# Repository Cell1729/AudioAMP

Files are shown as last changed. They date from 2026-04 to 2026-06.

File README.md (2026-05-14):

# AUDIOAMP

ヘッドフォンアンプの設計記録。

## 仕様

- INPUT : 3.5mmステレオジャック
- OUTPUT : 3.5mmステレオジャックと6.3mmステレオジャックをスイッチで切り替え
> 6.3mmOUTのみ変更
- ハイレゾに対応させる
- 出来る限り安くする

## 回路図

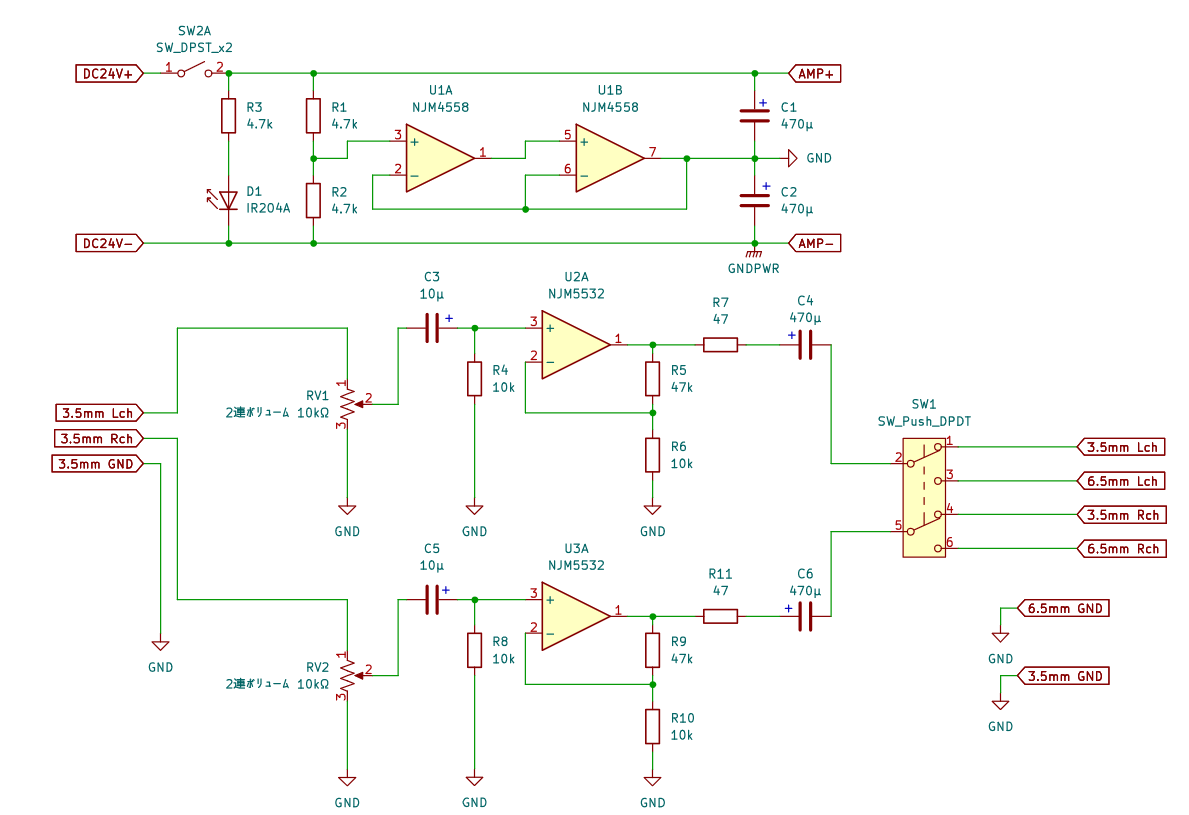
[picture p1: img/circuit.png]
circuit


### 特性

- 5.5倍利得
> 利得3倍に変更(20k/10k+1=3倍)
- 電源投下で緑のLEDを光らせる

## 部品

## 部品リスト

| 部品名 | 型番 | 数量 | 単価 | 小計 | 商品URL |
| :--- | :--- | :---: | :---: | :---: | :--- |
| アンプ | NJM5532DD | 1 | 90 | 90 | [リンク](https://akizukidenshi.com/catalog/g/g117706/) |
| アンプ 電源用 | NJM4558DD | 1 | 30 | 30 | [リンク](https://akizukidenshi.com/catalog/g/g111236/) |
| 小型2連ボリューム 10kΩA | JH16T2A103L20KC | 1 | 130 | 130 | [リンク](https://akizukidenshi.com/catalog/g/g116478/) |
| つまみ | ABS-28 | 1 | 30 | 30 | [リンク](https://akizukidenshi.com/catalog/g/g100253/) |
| 24VACアダプタ | AD-B240P100 | 1 | 1250 | 1250 | [リンク](https://akizukidenshi.com/catalog/g/g110658/) |
| ACアダプタコネクタ | MJ-14 | 1 | 70 | 70 | [リンク](https://akizukidenshi.com/catalog/g/g106342/) |
| 3.5mmステレオジャック | MJ-073H | 2 | 120 | 240 | [リンク](https://akizukidenshi.com/catalog/g/g106257/) |
| 6.3mmステレオジャック | MJ-189LP | 1 | 230 | 230 | [リンク](https://akizukidenshi.com/catalog/g/g106765/) |
| イヤホンジャック切り替え | - | 1 | 30 | 30 | [リンク](https://akizukidenshi.com/catalog/g/g115706/) |
| 電源用LED | OSG8HA3Z74A | 1 | 10 | 10 | [リンク](https://akizukidenshi.com/catalog/g/g111637/) |
| 電源スイッチ | 1MS1-T1-B1-M1-Q-N | 1 | 120 | 120 | [リンク](https://akizukidenshi.com/catalog/g/g103774/) |
| 4.7k抵抗 100本入り1% | MFS25F4K7B | 1 | 250 | 250 | [リンク](https://akizukidenshi.com/catalog/g/g108546/) |
| 10k抵抗 100本入り 1% | MFS25F10KB | 1 | 250 | 250 | [リンク](https://akizukidenshi.com/catalog/g/g108550/) |
| 47抵抗 100本入り 1% | MFS25F47RB | 1 | 250 | 250 | [リンク](https://akizukidenshi.com/catalog/g/g108518/) |
| 470μF 電解コンデンサ | 35ZLH470MEFC10X16 | 4 | 40 | 160 | [リンク](https://akizukidenshi.com/catalog/g/g102719/) |
| 10μF 電解コンデンサ | 50PX10MEFC5X11 | 2 | 10 | 20 | [リンク](https://akizukidenshi.com/catalog/g/g117897/) |
| アンプ ICソケット | 2227-8-3 | 1 | 110 | 110 | [リンク](https://akizukidenshi.com/catalog/g/g100017) |
| ユニバーサル基板 | - | 2 | 100 | 200 | [リンク](https://akizukidenshi.com/catalog/g/g100517/) |

合計金額: 3,470円

### ユニバーサル基板

[片面グラス・ユニバーサル基板 C type 72x47.5mm](https://akizukidenshi.com/catalog/g/g100517/)

## 入出力波形

> どの波形も緑が入力、青または赤が出力

### サンプル1

条件 : 0.5[V] 1[kHz]

Left Ch

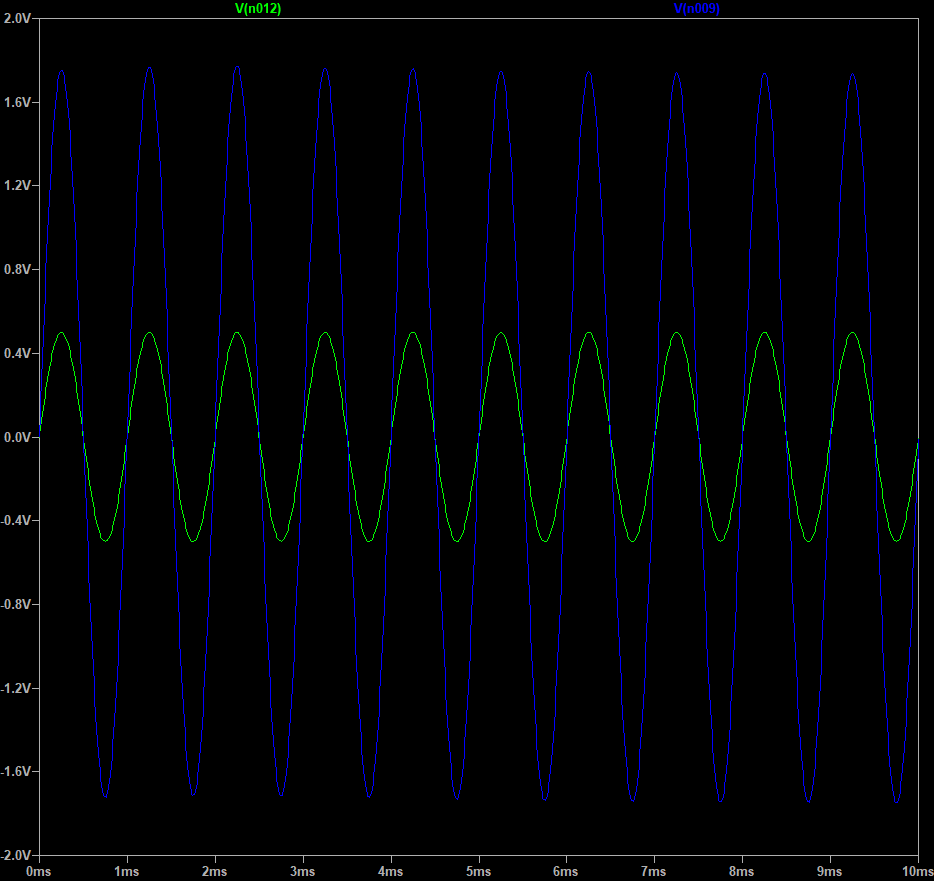
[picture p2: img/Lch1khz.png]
Lch


Right Ch

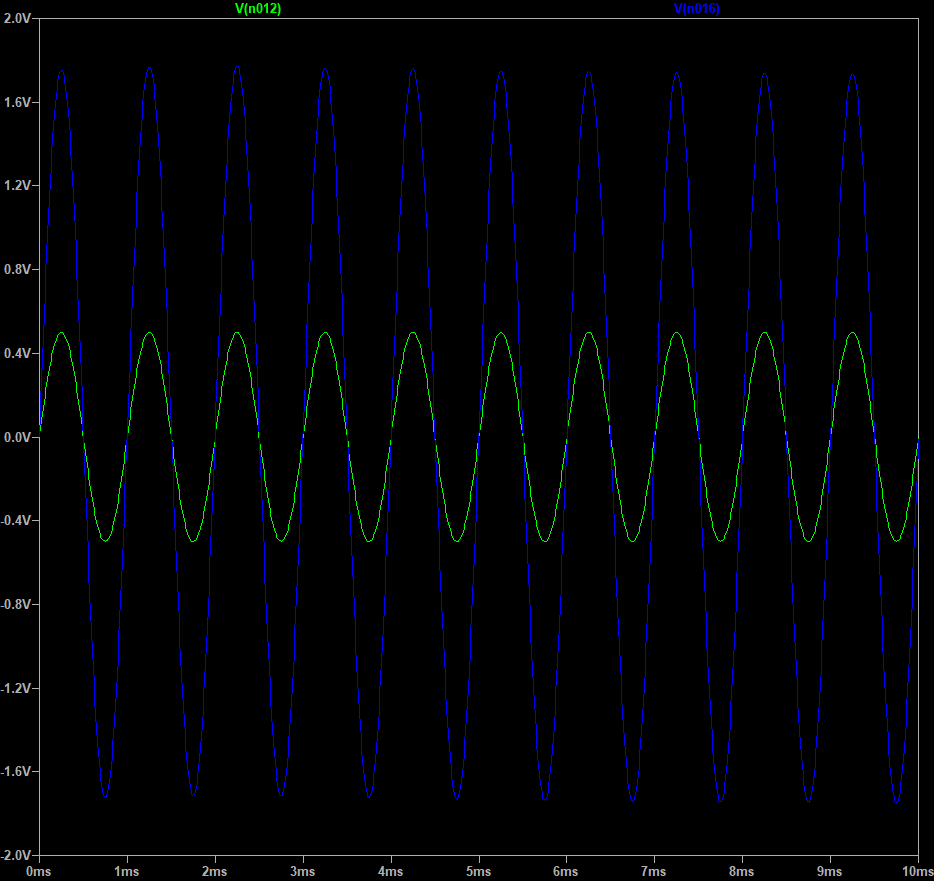
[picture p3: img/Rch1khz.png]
Rch


### サンプル2

条件 : 0.5[V] 96[kHz]

Left Ch

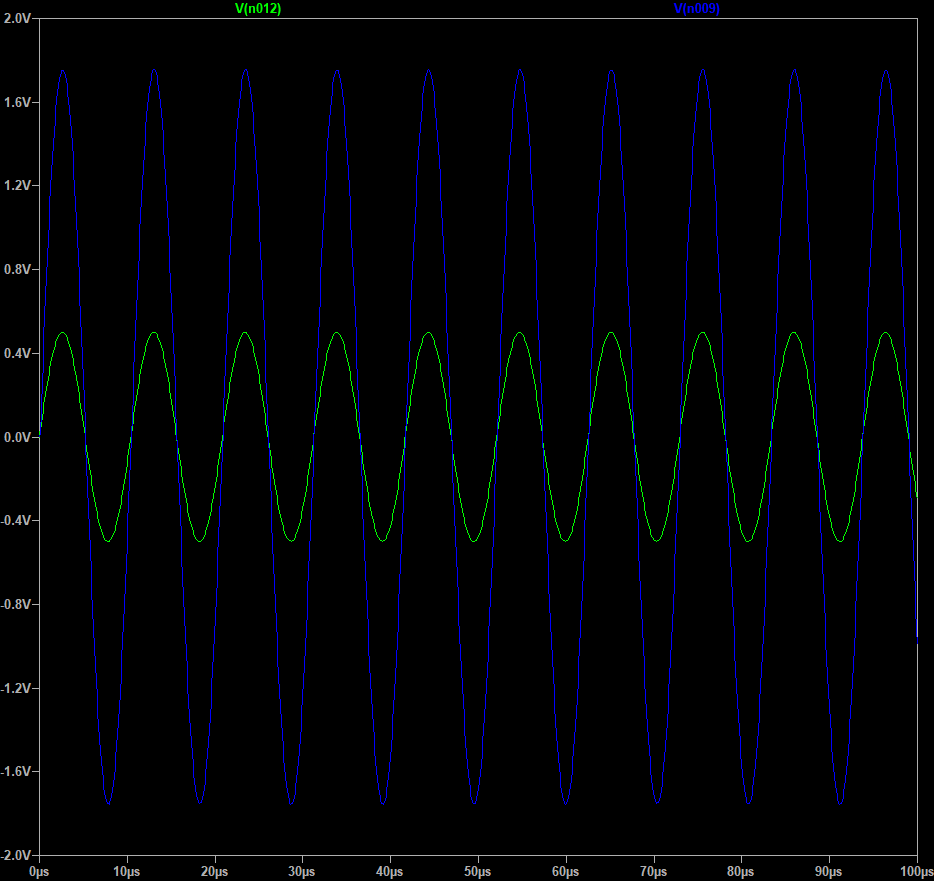
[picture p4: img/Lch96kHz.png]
LchHires


Right Ch

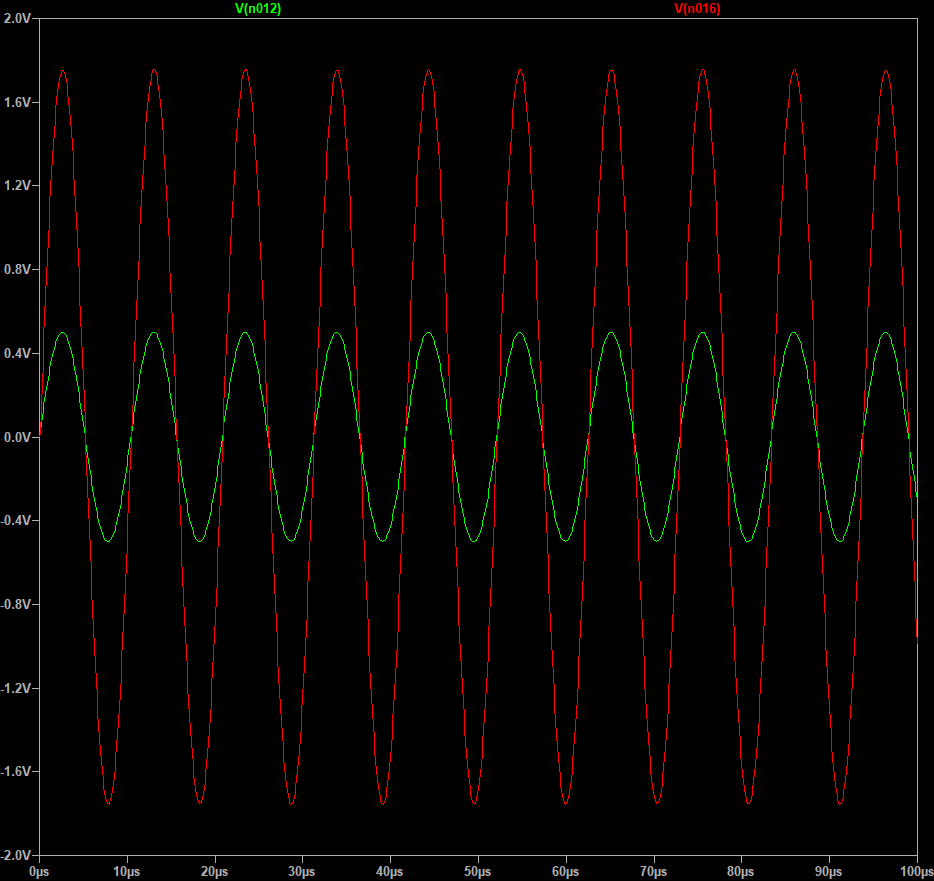
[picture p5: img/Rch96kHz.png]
RchHires


## その他

## `45kΩ`抵抗について

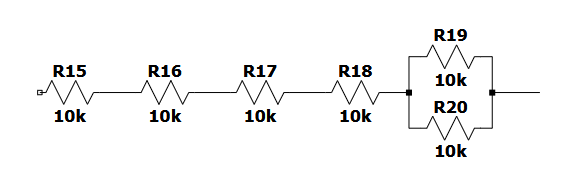
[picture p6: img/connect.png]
RConnect


このように上の図のように接続すれば抵抗値は
```
10k+10k+10k+10k+(10k*10k)/(10k+10k)=45k
```

## 基板構成

- 電源回路用基板
- アンプ搭載基板

## REF

- [AE-KIT45-HPAキット](https://akizukidenshi.com/goodsaffix/AE-KIT45-HPA.pdf)
- [電子パーツのコツ/ユニバーサル基板に挑戦](https://article.murata.com/ja-jp/article/challenge-the-universal-board)

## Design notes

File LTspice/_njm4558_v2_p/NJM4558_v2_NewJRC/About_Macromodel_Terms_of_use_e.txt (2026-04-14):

About Macromodel - Terms of use -
---------------------------------
1．Introduction

Our Macromodel (for use with PSpice) is a simulation program and not for use in actual product operation. 
It is not an alternative to the actual product. Please use this Macromodel to assist in the actual product operation check.

2．Special instruction

Nisshinbo Micro Devices is not responsible for changes, omissions, inaccuracies, and designs caused by the product Macromodel. 
Moreover, Nisshinbo Micro Devices does not take any responsibility if customers use this information for other purposes.
Nisshinbo Micro Devices requires customers to take full responsibility for their use of any information acquired through Macromodel. 
In addition, Nisshinbo Micro Devices does not give consent agreement or patent rights with regards to circuits described 
in relevant documents.

3．Usage and operating requirements

3-1．Operating requirements

Our Macromodel and related information have been created for use with OrCAD/Pspice, which is produced by Cadence Design Systems, Inc. 
in the United States. 
Nisshinbo Micro Devices is not liable for performance of the Macromodelin all computer systems.

3-2.Conditions of use

The product Macromodel should be used under agreement of the conditions contained below.

i. The product Macromodel is offered with product-specific, present quality. 
Nisshinbo Micro Devices does not take responsibility for Macromodel operation once Macromodel is integrated into customers’ 
circuits or systems.

ii. The product Macromodel is subject to change without notice. Please refer to the latest version of data-sheet or delivery specifications 
for detailed information regarding each product.

Update October 01,2021

---------------------------------
Nisshinbo Micro Devices Inc.

(C) Nisshinbo Micro Devices Inc. All Rights Reserved.

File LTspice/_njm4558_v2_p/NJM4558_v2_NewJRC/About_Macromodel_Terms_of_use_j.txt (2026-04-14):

マクロモデル利用規約
---------------------------------
1．はじめに

日清紡マイクロデバイス株式会社（以下「当社」といいます。）が提供する製品マクロモデル （=PSpice用マクロモデル）は、
実製品の動作を模擬できる手段の一つです。 
ただし、製品マクロモデルを使った回路シミュレーションは、実製品を用いた 試作基板などによる評価方法の代替とすることを
目的としておりません。 あくまで実製品の動作を確認するための一助としてお使いください。

2．特記事項

製品マクロモデルおよび関連情報は、正しい情報であるという前提で 提供していますが、
当社は、製品マクロモデルから生ずる変更、省略、不正確さ、 または設計に関して責任を負わないものとします。 
また、当社は、この情報を他の目的に利用した場合の責任も負わないものとし、 この情報の使用は全て利用者の自己責任とみなします。 
なお、当社は、関連文書中に記載されている回路に関して、利用許諾または 特許権を付与するものではありません。

3．ご利用にあたって

3-1．動作環境

当社が提供する製品マクロモデルおよび関連情報は、米Cadence社製の OrCAD/PSpiceで用いることを目的に作成しています。 
製品マクロモデル化にあたっては充分な注意を払っておりますが、全ての コンピュータ・システム上での正常動作に対して責任を負いかねます。

3-2．利用条件

製品マクロモデルは、以下のご利用条件にご同意の上、これをご利用ください。

ⅰ．製品マクロモデルは製品固有の現状品質で提供され、お客様の回路または システムと組み合わせた時の製品マクロモデルの動作に対して、
当社はいかなる 責任も一切負いかねます。
ⅱ．当社は、予告なく製品マクロモデルを変更することがあります。 個別製品の詳細情報は、最新版のデータシートまたは納入仕様書を 
参照してください。

4．その他

米Cadence社製のOrCAD/PSpiceを用い、かつ、その国内代理店である イノテック株式会社（https://www.innotech.co.jp/products/orcad/)と
OrCAD/PSpiceについて 保守契約締結をされているお客様につきましては、当社が提供する製品マクロモデルの PSpice上での使用方法について、
イノテック株式会社より技術支援が受けられます。

2021年10月1日更新

---------------------------------
日清紡マイクロデバイス株式会社

・本文書の記載内容は予告なく変更することがあります。
・本文書に記載されている、社名、商品名などは各社の商標または登録商標です。
・本文書の掲載内容を許可なく複製、転載する事を禁止いたします。
(C) Nisshinbo Micro Devices Inc. All Rights Reserved.

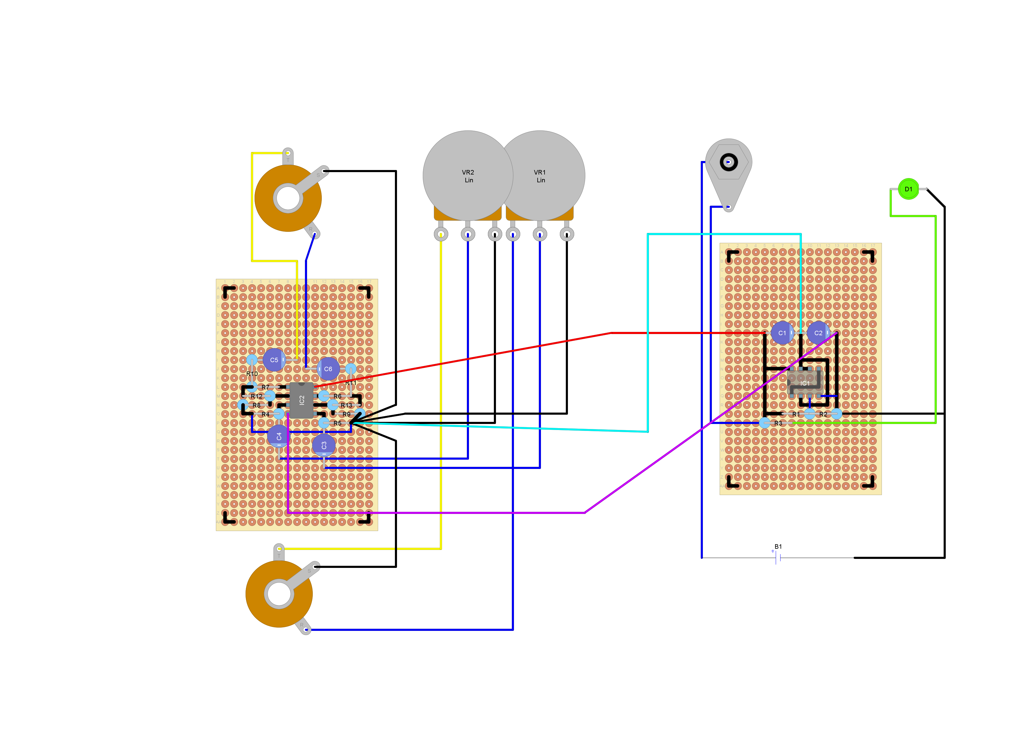
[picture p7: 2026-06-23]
layout/layout_real.png

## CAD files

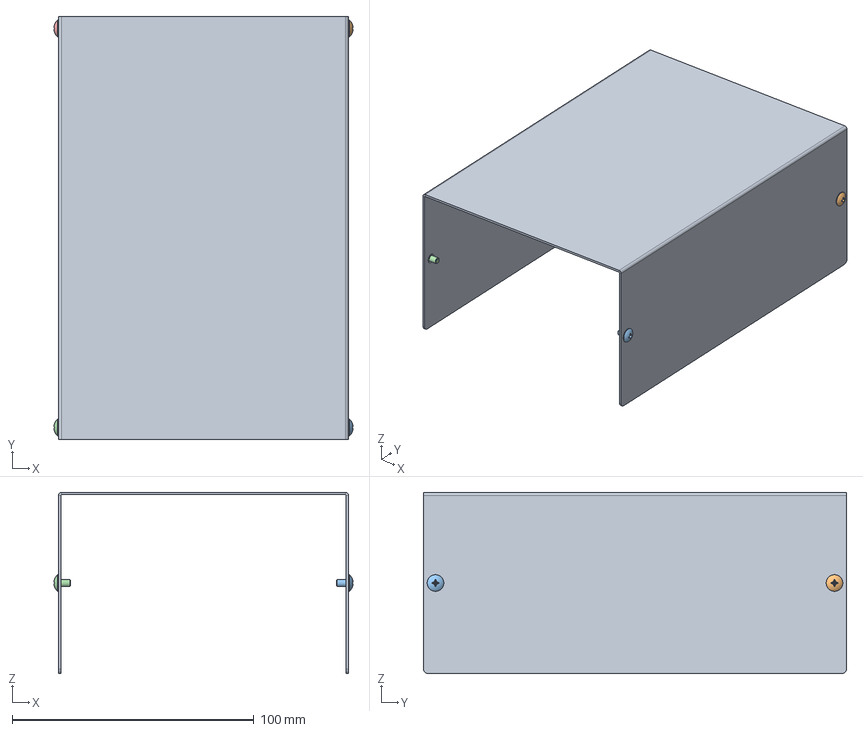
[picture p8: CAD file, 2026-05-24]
case/CAD/case.FCStd
123.6 x 175.0 x 75.0 mm
MB12-8-18_cover
M3x5
M3x001
M3x002
M3x003

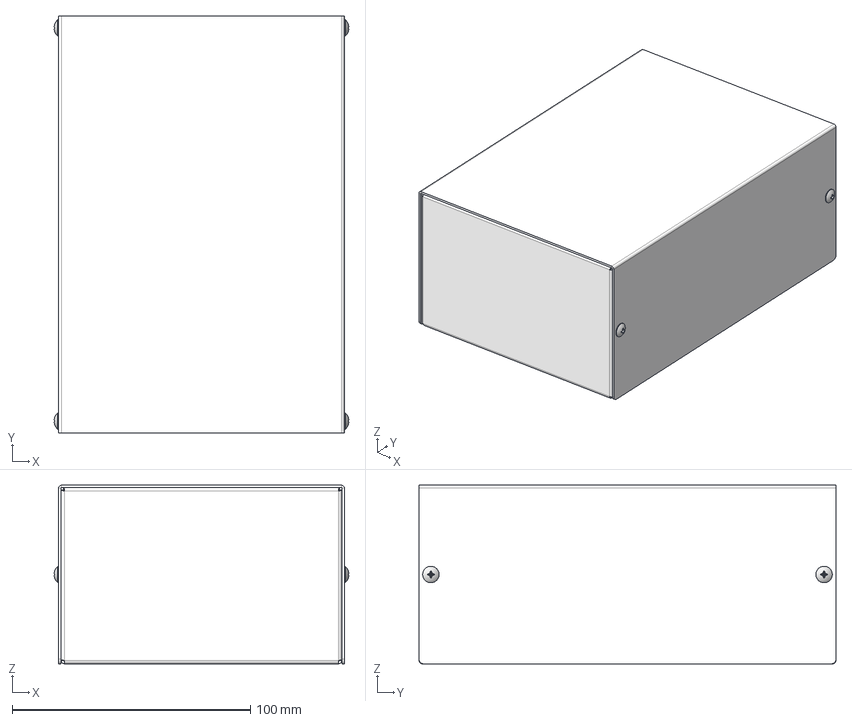
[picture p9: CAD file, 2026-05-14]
case/CAD/MB12-8-18.stp
123.6 x 175.0 x 75.0 mm
MB12-8-18_cover
MB12-8-18_ｼｬｰｼ
M3x5 x 4

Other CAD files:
case/case.dxf

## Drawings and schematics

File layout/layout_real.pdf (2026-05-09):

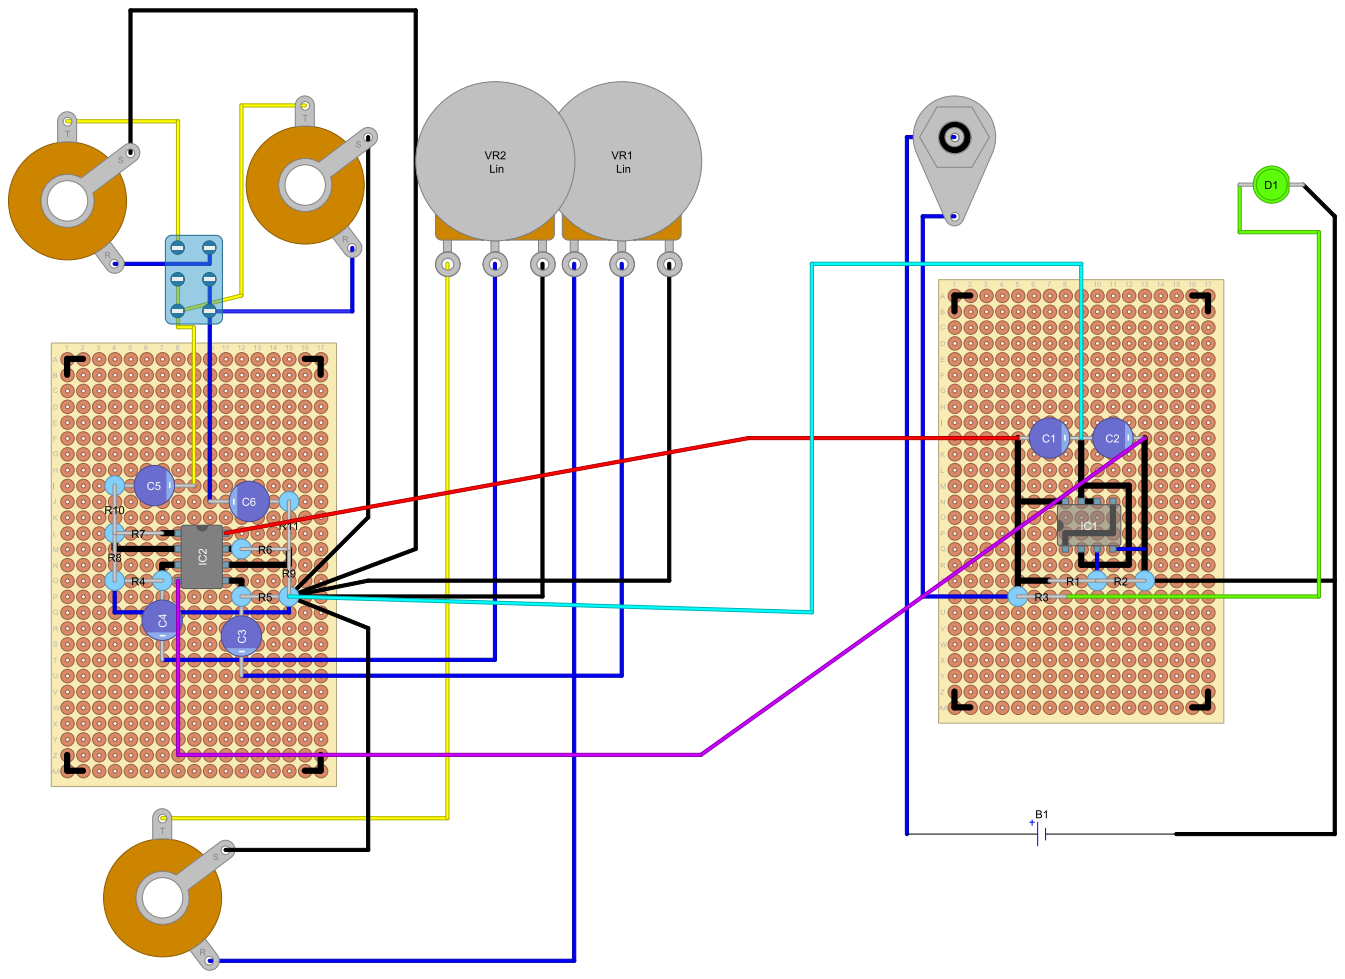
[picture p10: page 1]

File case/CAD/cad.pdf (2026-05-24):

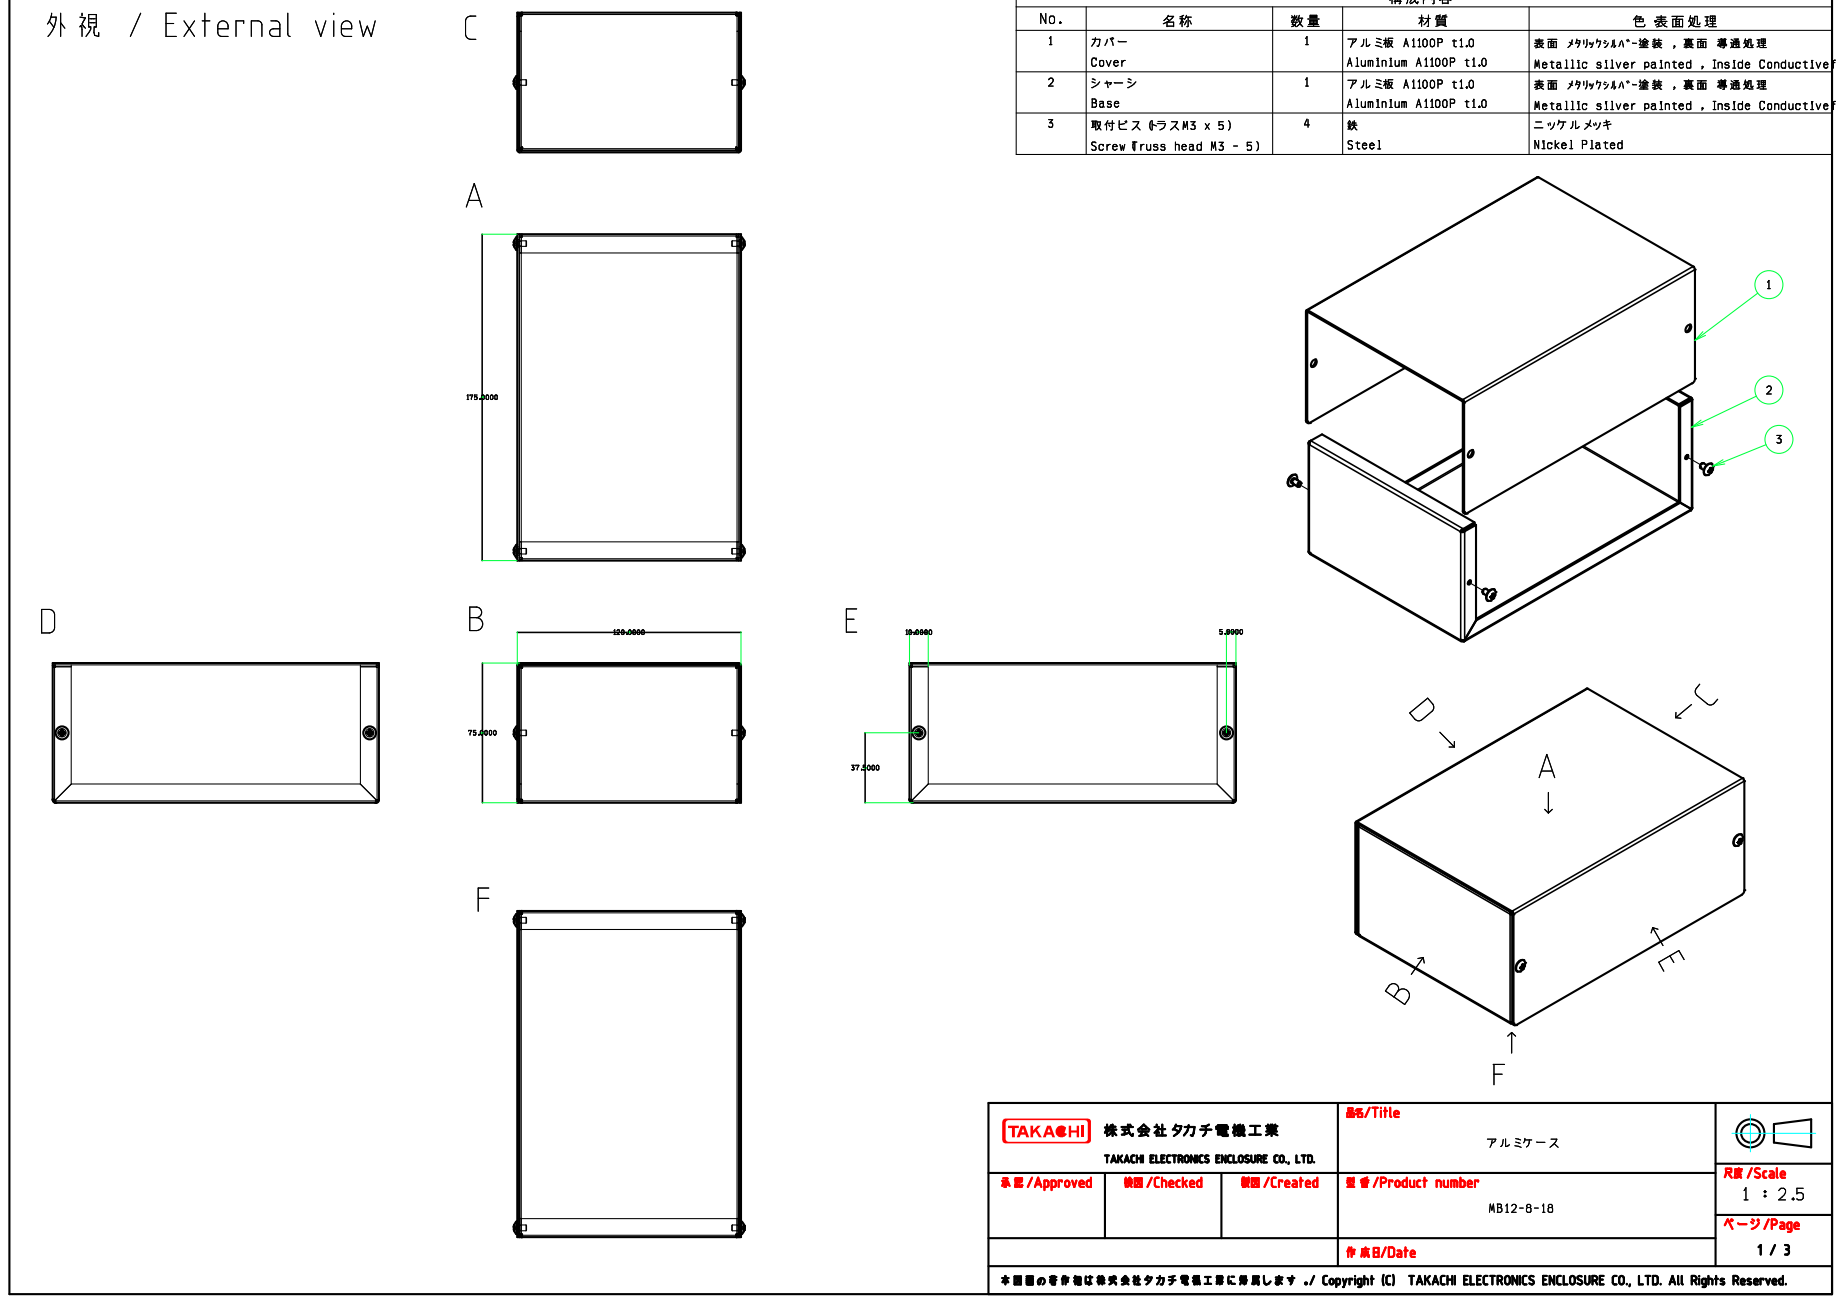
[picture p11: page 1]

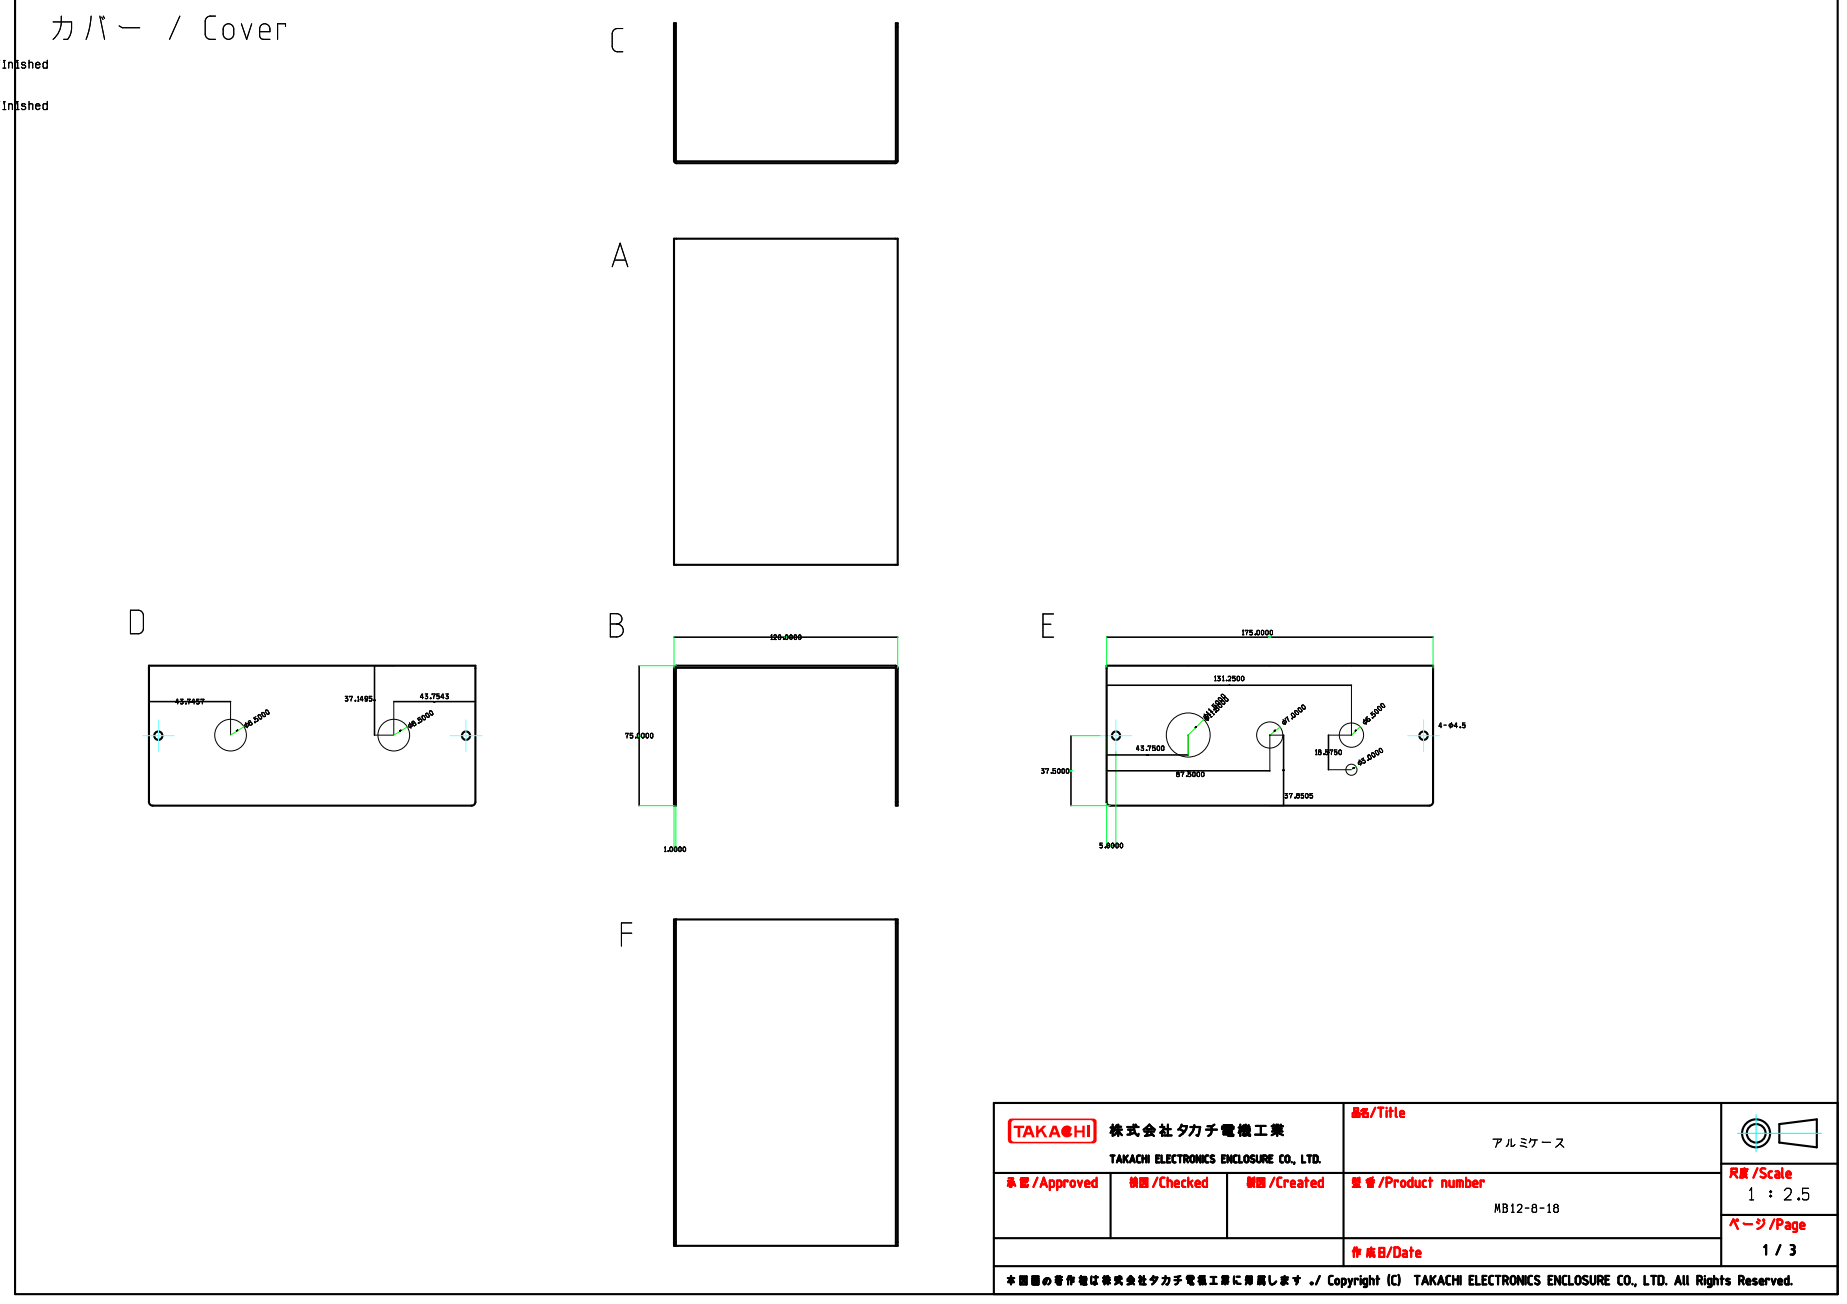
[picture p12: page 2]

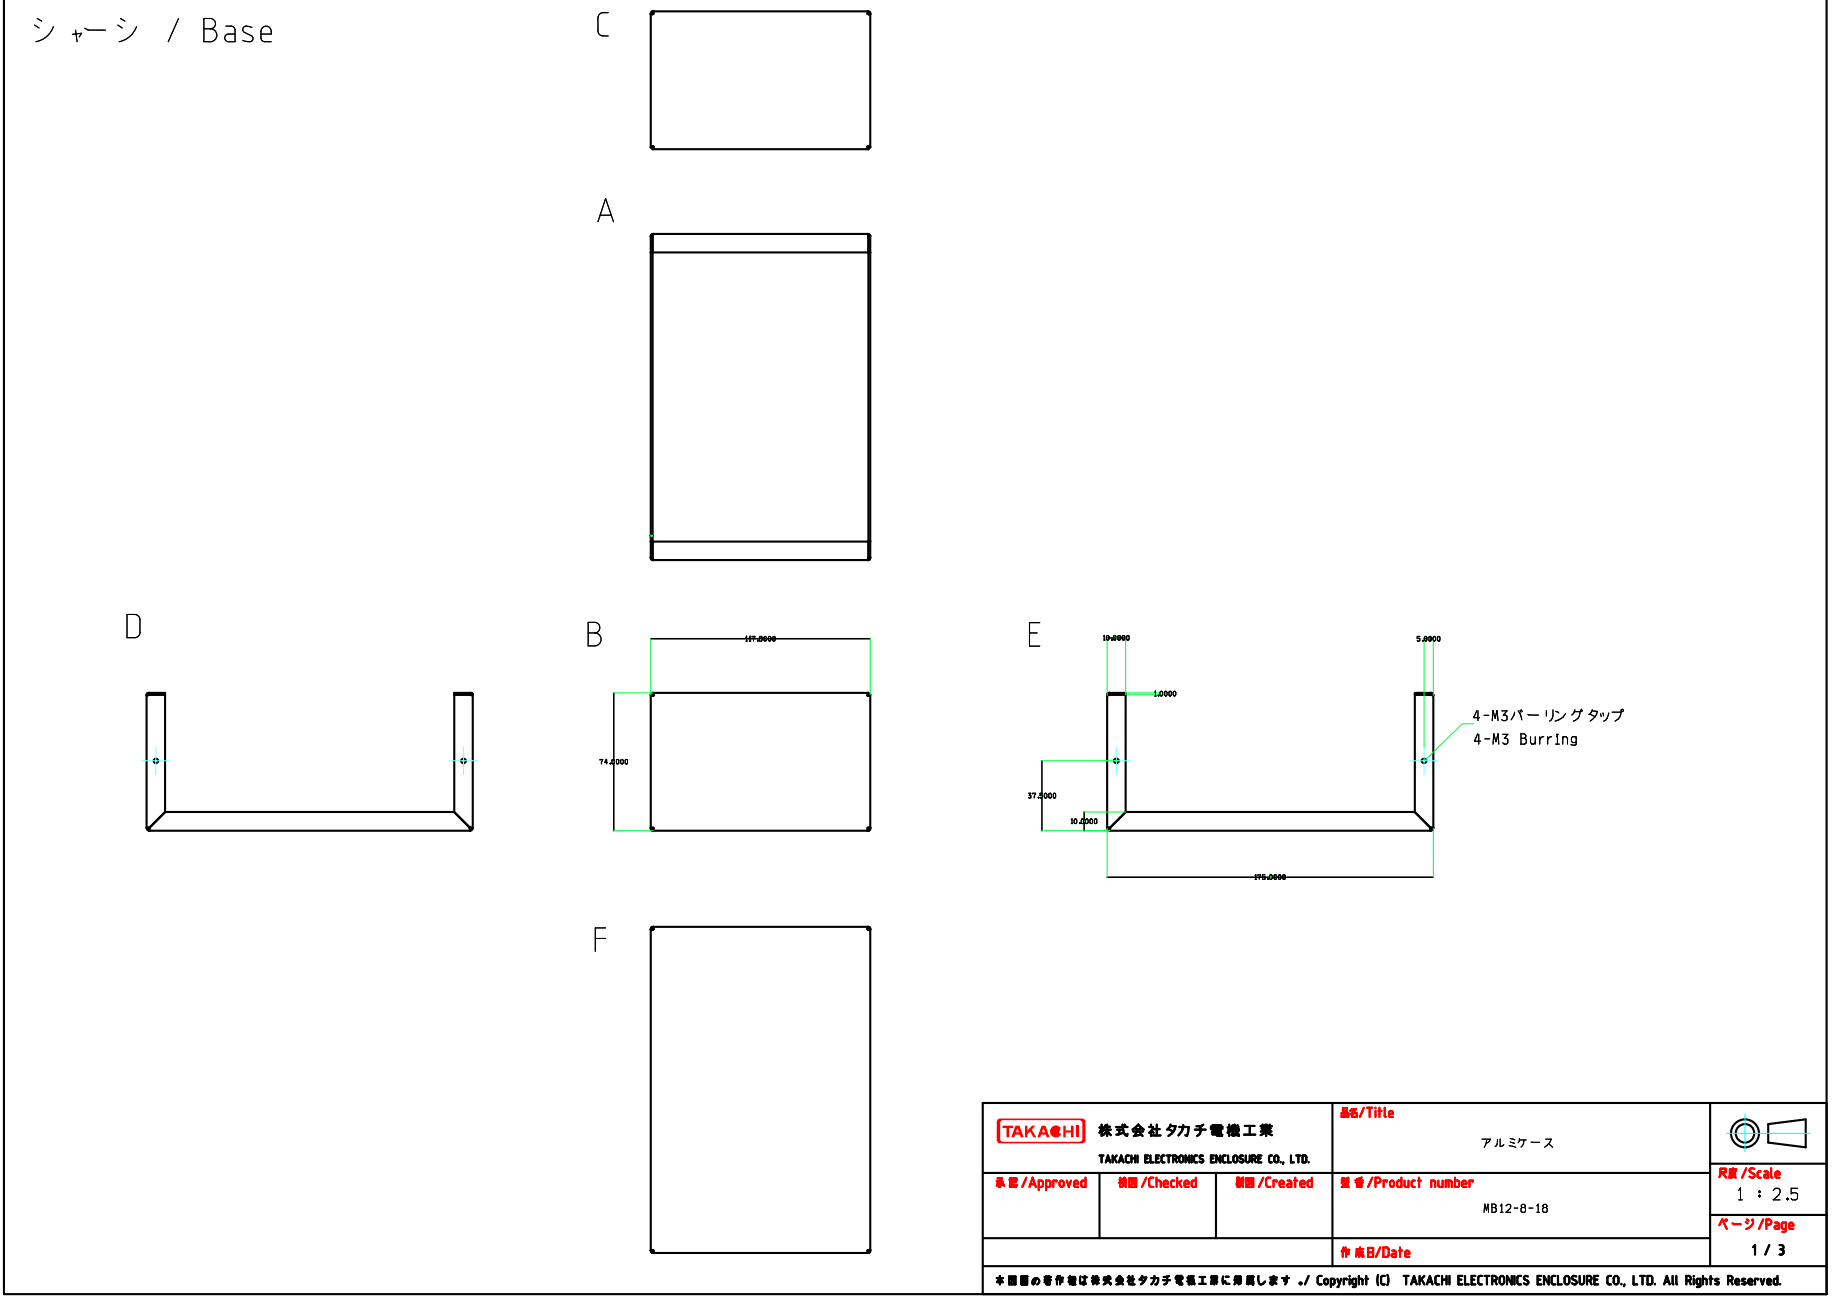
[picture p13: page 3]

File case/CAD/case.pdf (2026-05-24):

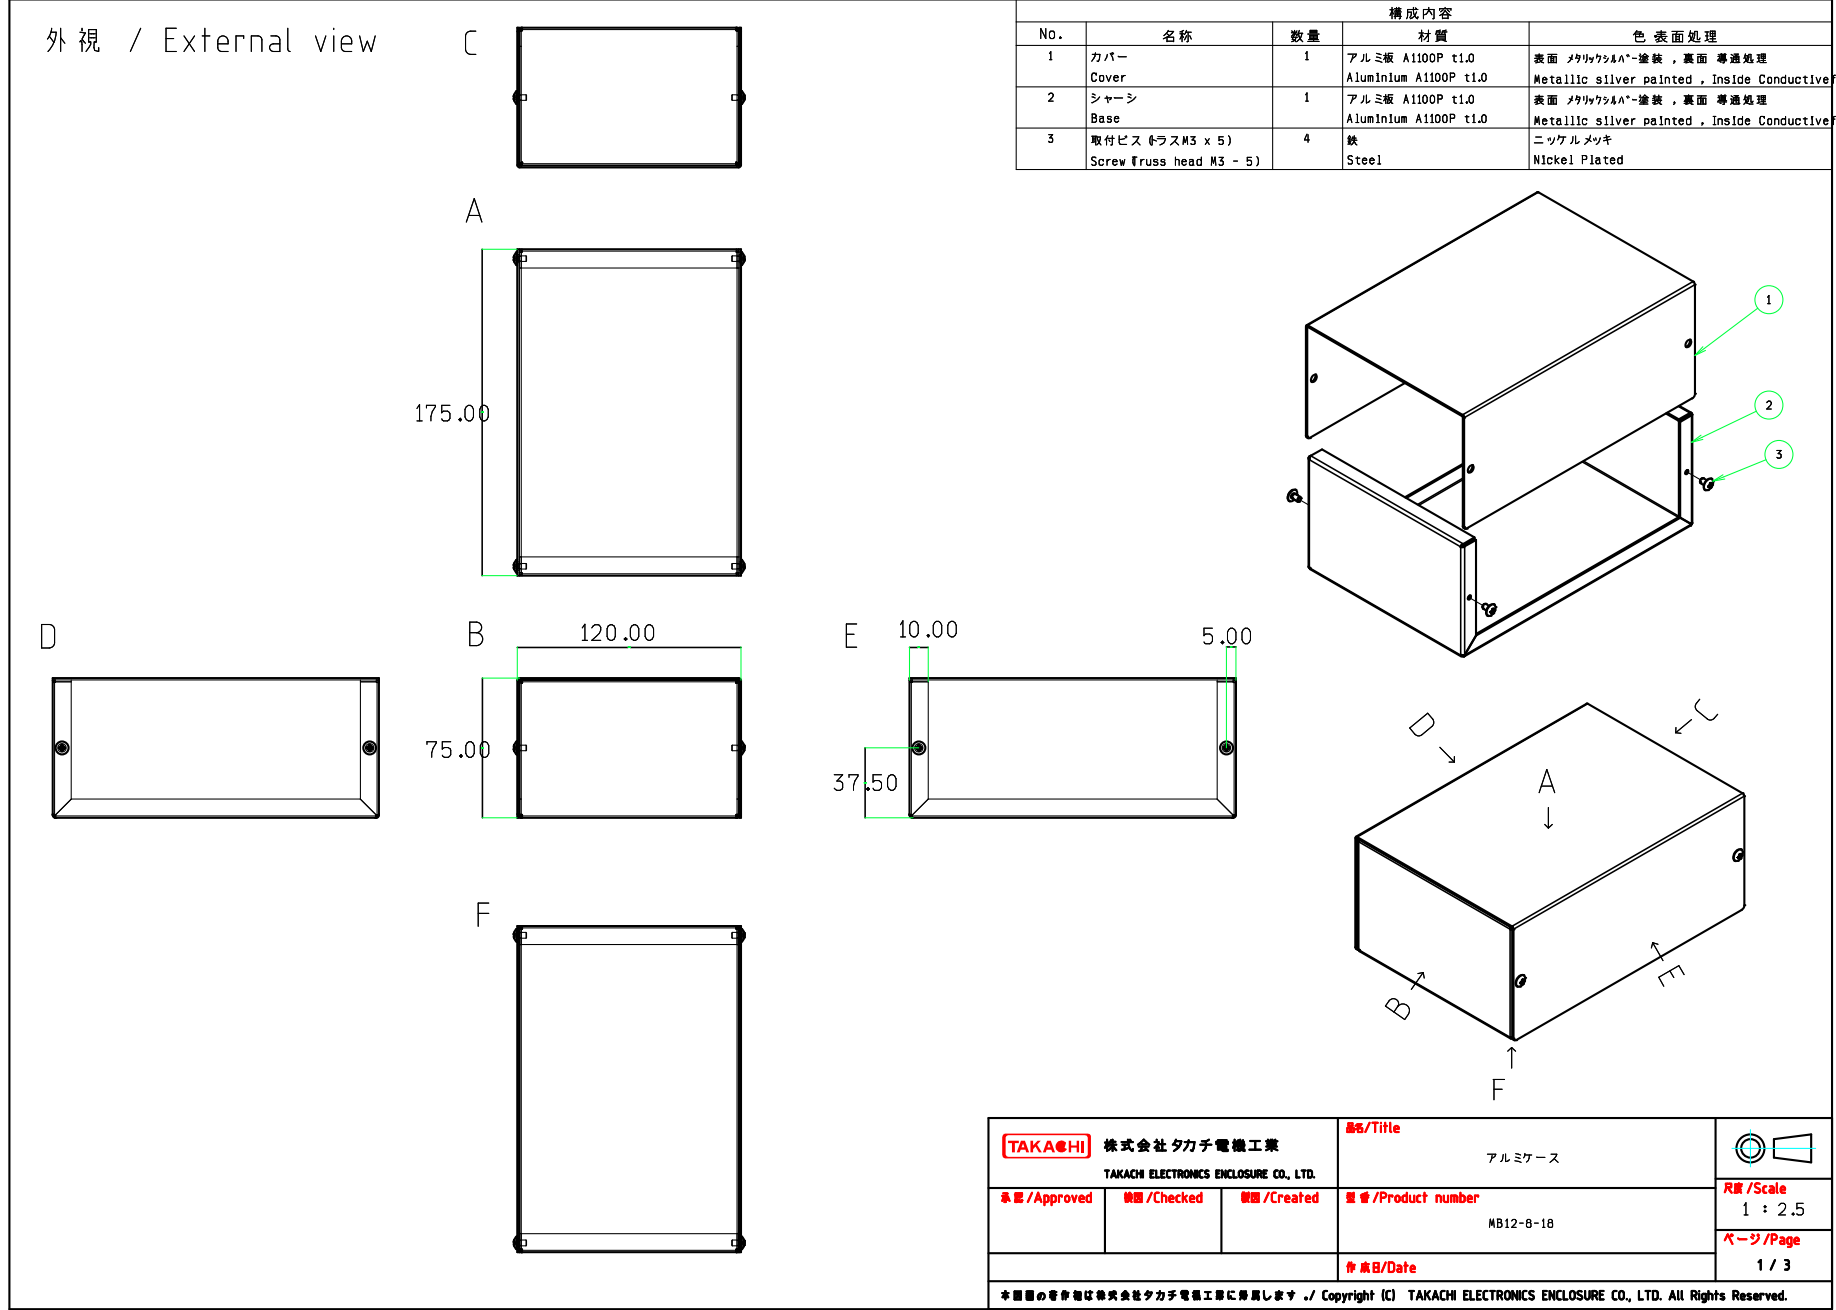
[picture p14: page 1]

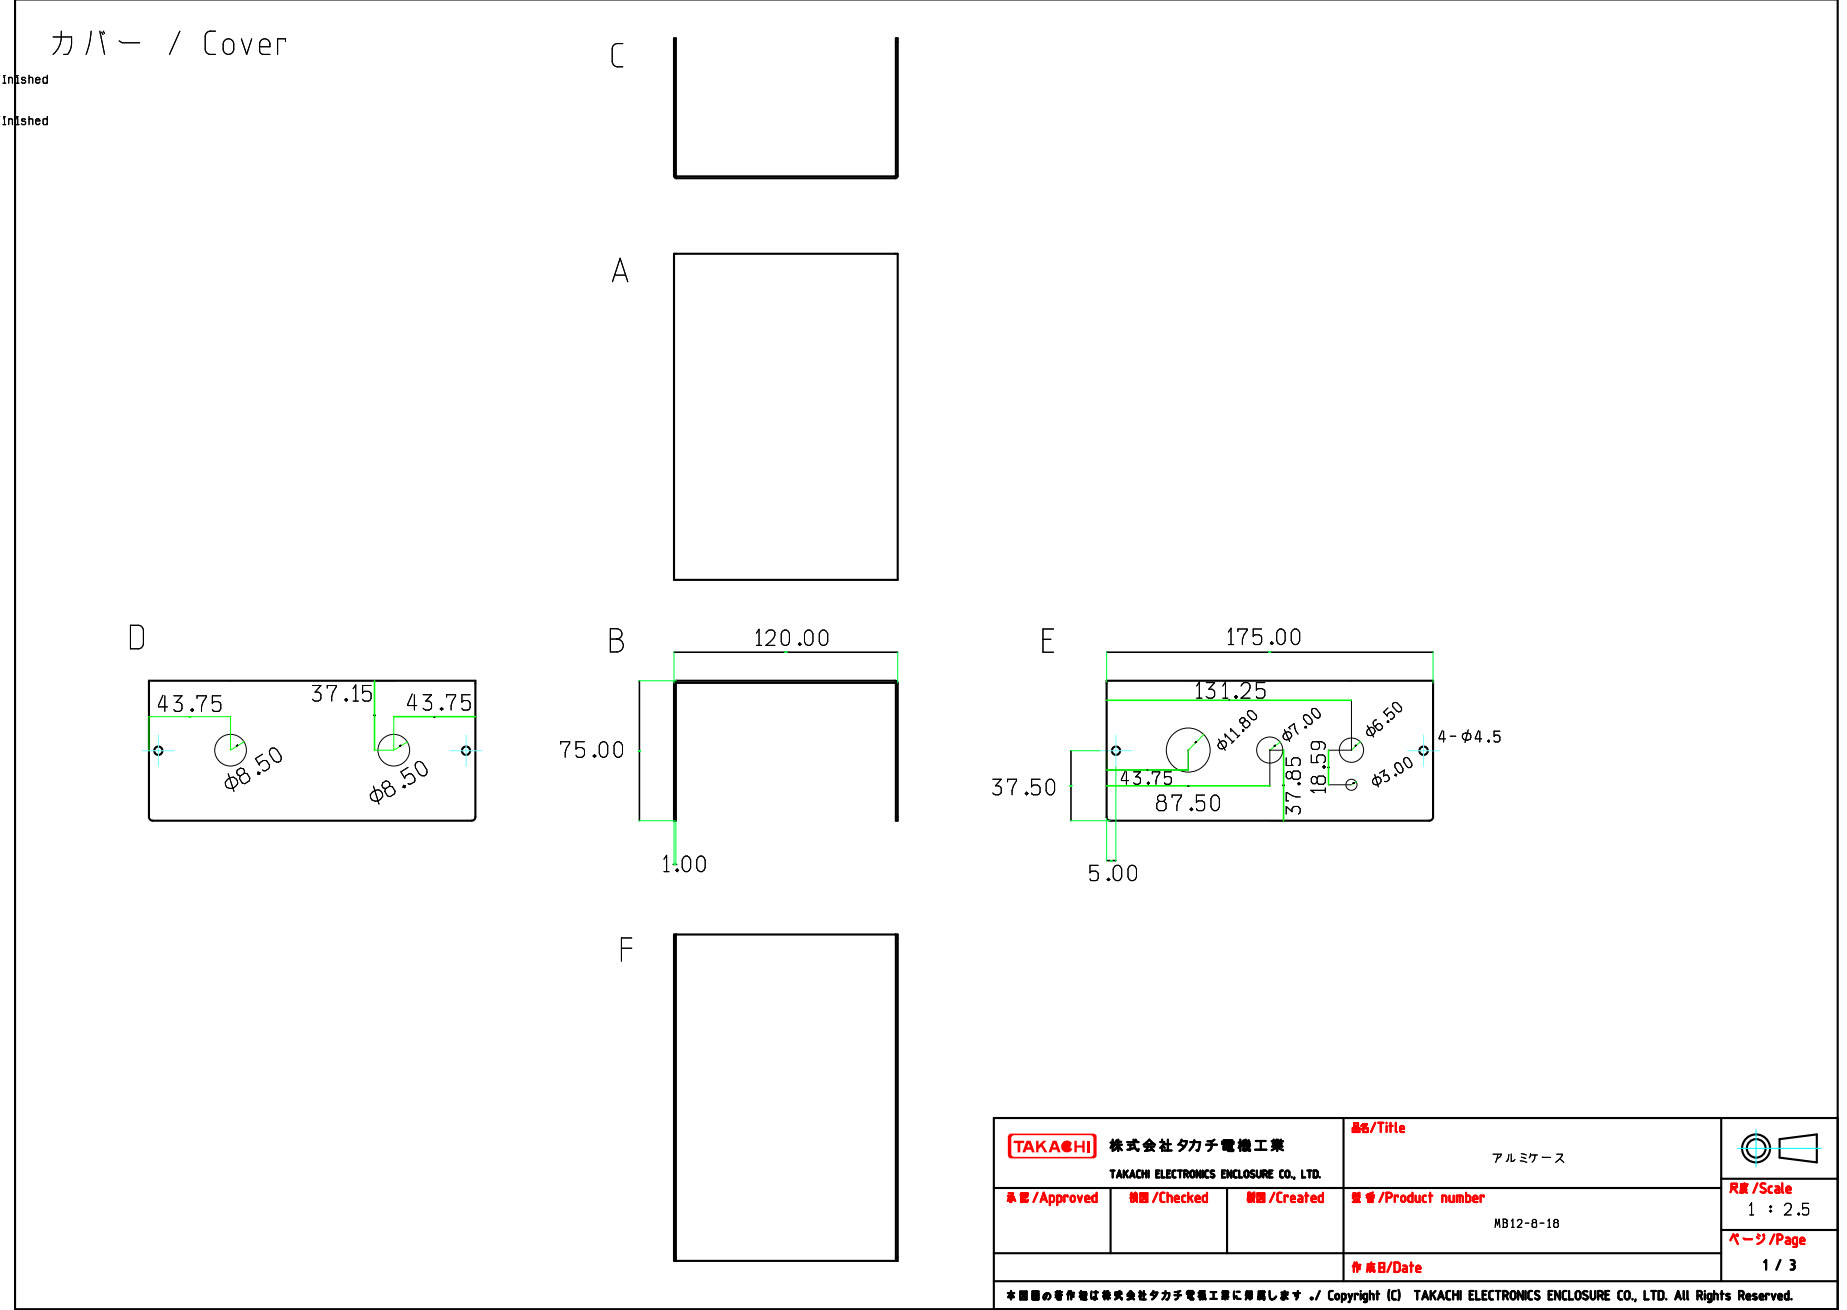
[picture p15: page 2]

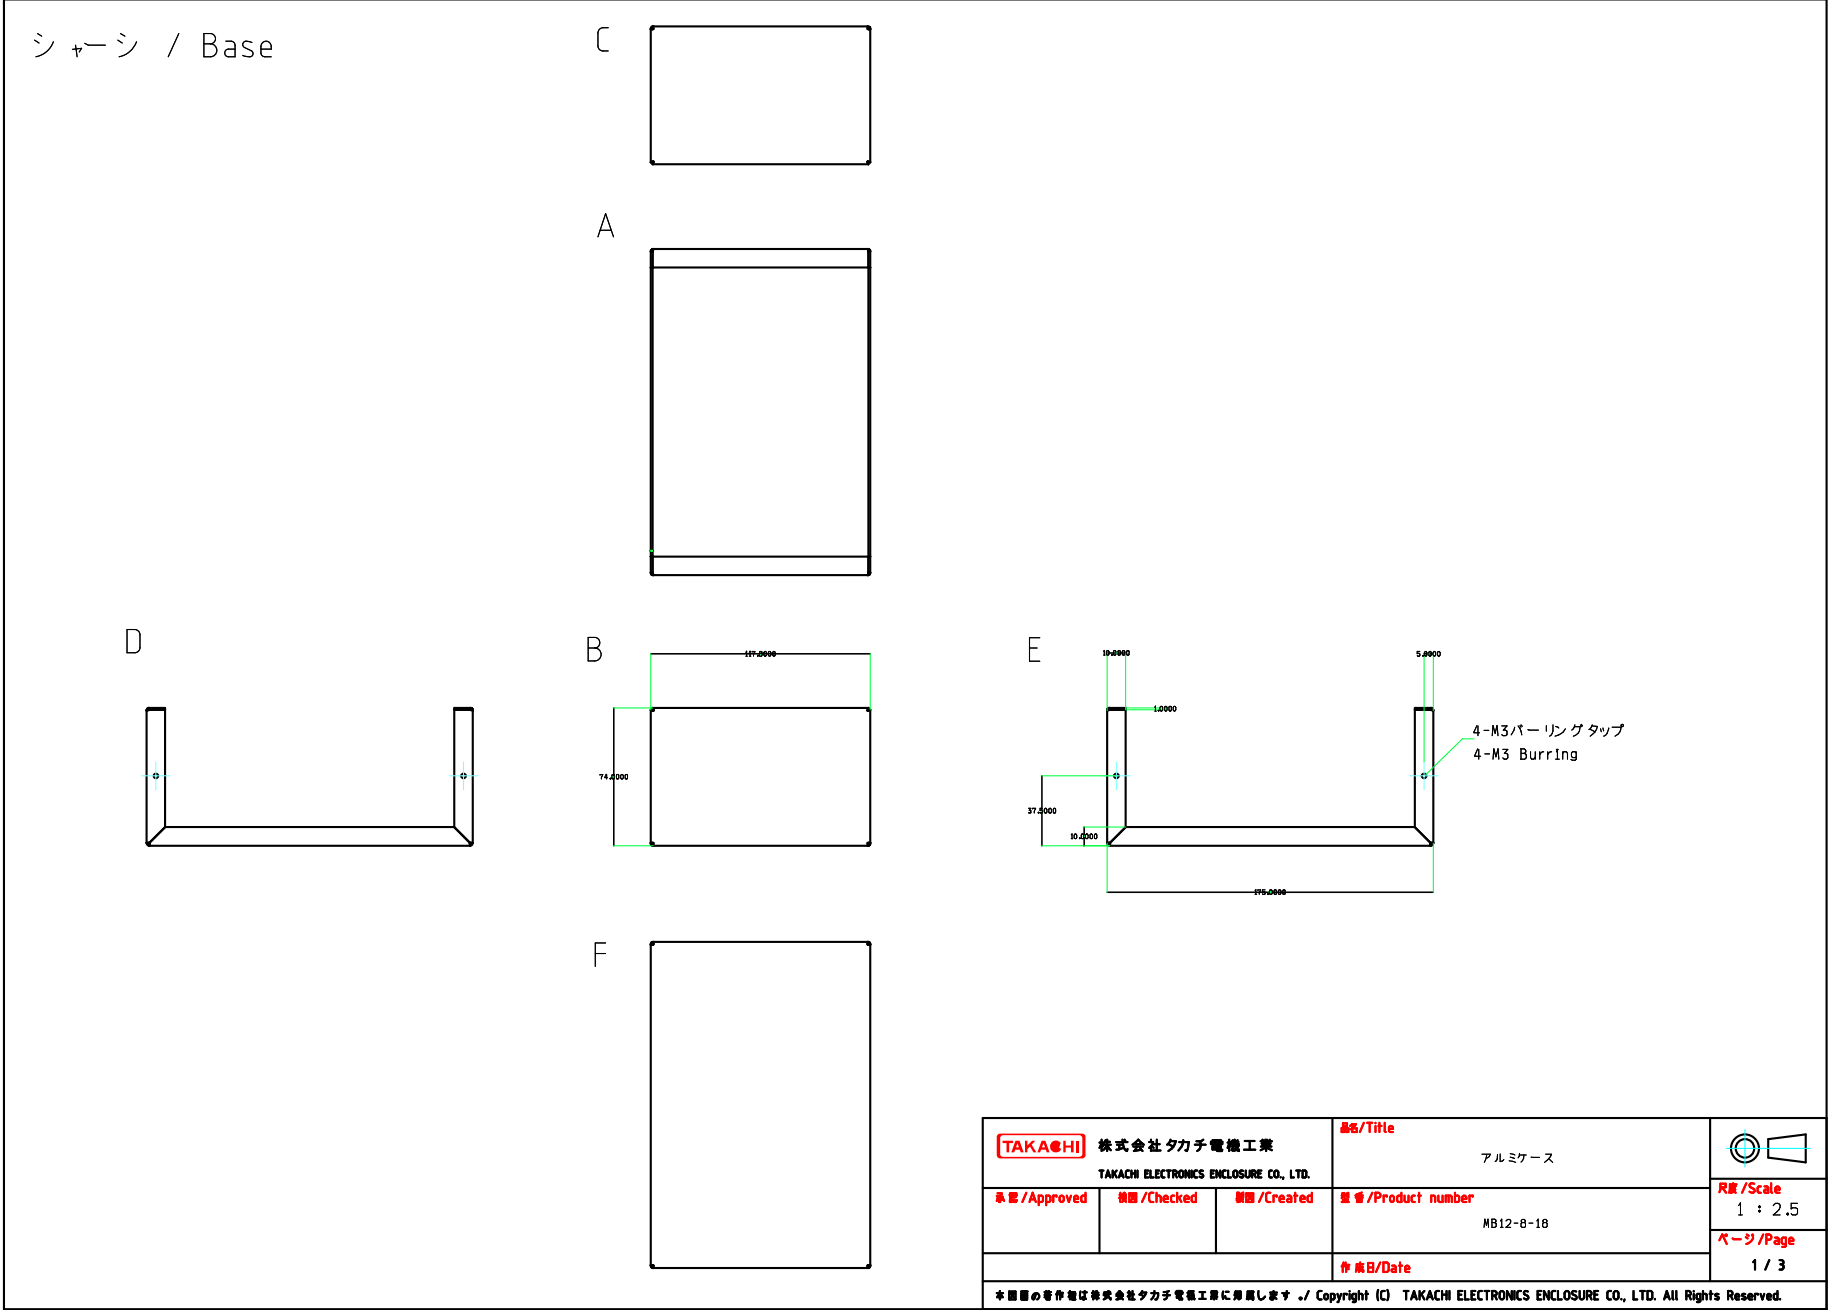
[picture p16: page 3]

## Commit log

2026-04-12 add : 回路図
    [circuit.kicad_pcb, circuit.kicad_sch]
2026-04-15 add : REAMDE.md
    [circuit.kicad_sch]
2026-04-15 update : 画像の名前を変更
2026-05-03 update : README.md
    基板構成を追記
    パーツの金額ミスを修正
2026-05-03 add : ユニバーサル基板のレイアウト
    その他回路図の間違いを修正
    [circuit.kicad_sch]
2026-05-03 update : circuit image
2026-05-03 update : power circuit
    [circuit.kicad_sch]
2026-05-03 add : case part
    [circuit.kicad_sch]
2026-05-04 update : case front UI
2026-05-09 update : layout circuit
    LOW Noise model
2026-05-14 add : CAD FILE
    TAKACHIに依頼するための図面ファイルを追加
    拡張子.stpはテンプレートとして残しておく
    [MB12-8-18.stp, case.FCStd]
2026-05-24 add : case CAD files
    [case.FCStd, case.dxf]
